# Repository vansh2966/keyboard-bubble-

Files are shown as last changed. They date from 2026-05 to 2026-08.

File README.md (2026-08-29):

well story behind is that i was always wanted mechanical keyboards, that cool looking keyboards with crazy 
lighting effects and keycaps. so i thought why not make one myself, i will learn lot new things, desgin my first PCB and also get myself my own custom keyboard. so started it, did some research, components 
and everything related to it

it a keyboard that helps u write with per key rgb which u can control and create some cool and awsome effects.
u can use it wired or wireless, with hotswappable keys. u can just change the type of keys if u wnat. 
all key anti ghost, with 65% layout and 68 keys which u can assign anything and also create macros.

in the base there highted screw holes, first u put the the stabalizers in the PCB then place the PCB on the heighted holes then the plate and screw it up with 4 m2 screws. if u want u can add a foam layer between
the PCB and the plate. and in the end u can add the keycaps.

**How to Build it**
- get all the matrials including 3d printed parts
- soldering all the things in PCB
- place your PCB in case aliging with the screw holes
- place your plate on top that, u can also palce foam btween plate and pcb.
- screw up all 4 screws
- take keys your keys and stick them
- put your keycaps on the top
- take your microcontroller and plug it in
- make sure its in bootloader mode
- take the firmware files and put them in the chip
- ready to use it

**How to use it**
- u can use it wired or wireselly
- connect it ur computer using cable or bluthooth
- start typing

baseee

the base of the keyboard. i wanted it look premium so i made the thick bezels, u can mount the pcb and plate with screws

complete
WhatsApp Image 2026-07-14 at 11 50 17 PM

this all together looks with brown and black keys. maybe i will change it later if i want 

the completed build with gengar themed keys:
WhatsApp Image 2026-07-14 at 11 50 19 PM
WhatsApp Image 2026-07-14 at 11 50 19 PM

bin
pcb
pcb back

the PCB  tool all of times, the scematics routing, fixing small errors and getting tons of errors in DRC. but in the end 
it was worth it

i updated the CAD file and made a new design. fixed few error that learned after ordering the old one. not muhc much of a change but ig its better and also looks better


## 📦 Bill of Materials (BOM)

| Component | Quantity | Total Price (INR) | Sourcing Link |
| :--- | :---: | :---: | :--- |
| **XIAO ESP32 nRF52840 Plus** | 1 | ₹2,300 | [Mouser Link](https://www.mouser.in/ProductDetail/Seeed-Studio/102010672?qs=sqEgtWRSLJ0SuHAgTfdO0A%3D%3D) |
| **3.7V Lithium Polymer Battery** | 1 | ₹397 | [Amazon Link](https://www.amazon.in/gp/product/B0GM6RKSB4/) |
| **Slide Switch (3-Pin)** | 1 | ₹100 | [Amazon Link](https://www.amazon.in/gp/product/B0D33BLGBB/) |
| **Mechanical Switches (Kailh Red)** | 70 | ₹1,260 | [Cosmic Byte Link](https://www.thecosmicbyte.com/product/kailh-mechanical-switches-for-swappable-keyboards-pack-of-10/) |
| **Kailh MX Hotswap Sockets** | 70 | ₹870 | [Neomacro Link](https://neomacro.in/products/kailh-mx-hotswap-socket) |
| **Diodes (1N4148W)** | 100 | ₹1,944 | [DigiKey Link](https://www.digikey.in/en/products/detail/mcc-micro-commercial-components/1N4148W-TP/717196) |
| **Stabilizers (PCB Mount)** | 1 | ₹2,400 | [Amazon Link](https://www.amazon.in/gp/product/B07K8HP6KC/) |
| **Keycaps** | 1 | ₹5,335 | [Amazon Link](https://www.amazon.in/gp/product/B0FS27BG38/) |
| **LEDs (SK6812 Mini-E Reverse)** | 100 | ₹6,310 | [Amazon Link](https://www.amazon.in/gp/product/B0D5LGQ629/) |
| **Decoupling Capacitors** | 100 | ₹100 | [Robu Link](https://robu.in/product/1uf-capacitor-smdc-0402-pack-of-50/) |
| **Transistor (SM712 TVS)** | 1 | ₹28 | [DigiKey Link](https://www.digikey.in/en/products/detail/smc-diode-solutions/SM712/16584910) |
| **PCB Fabrication** | 1 | ₹5,918 | [JLCPCB Link](https://jlcpcb.com) |
| **3D Printing Service** | 2 | ₹1,729 | [Robu Link](https://robu.in/product/3d-printing-service1/) |
| **Resistors** | 2 | Already have it | - |
| **2 in 1 Hot Wind Gun Solder Iron SMD Rework Soldering Station ** | 1 | ₹4391 | [Amazon Link](https://www.amazon.in/gp/product/B0F4QYBK7Y/ref=ox_sc_act_title_1?smid=A3T8K809Q96RB6&psc=1) |
| **Soldering paste** | 1 | ₹399 | [Amazon link](https://www.amazon.in/gp/product/B0DL4K4WWQ/ref=ox_sc_act_title_1?smid=A28W8MJHJ0JA2F&psc=1) | 
| **Miscellaneous** | - | ₹1,000 | - |
| ─── | ─── | ─── | ─── |
| **TOTAL COST** | **-** | **₹34,482 ($361 USD)** | **Fully Sourced** |

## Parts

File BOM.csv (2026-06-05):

COMPONENT | QTY | price | link
XIAO ESP32 nRF52840 plus | 1 | 2300 | https://www.mouser.in/ProductDetail/Seeed-Studio/102010672?qs=sqEgtWRSLJ0SuHAgTfdO0A%3D%3D
3.7V Lithium Polymer Battery | 1 | 397 | https://www.amazon.in/gp/product/B0GM6RKSB4/ref=ox_sc_act_title_5?smid=A3QQB9C2QXM7ZJ&psc=1
slide swtich 3pin | 1 | 100 | https://www.amazon.in/gp/product/B0D33BLGBB/ref=ox_sc_act_title_2?smid=A1UUD7CBBVVXIG&psc=1
Mechanical Switches | 70 | 1260 | https://www.thecosmicbyte.com/product/kailh-mechanical-switches-for-swappable-keyboards-pack-of-10/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
Kailh Hotswap Sockets | 70 | 870 | https://neomacro.in/products/kailh-mx-hotswap-socket?variant=49467139227926&country=IN&currency=INR
Diodes (1N4148W) | 100 | 1944 | https://www.digikey.in/en/products/detail/mcc-micro-commercial-components/1N4148W-TP/717196
Stabilizers (PCB mount) | 1 | 2400 | https://www.amazon.in/gp/product/B07K8HP6KC/ref=ox_sc_act_title_3?smid=AKPH4HW0FR8BT&psc=1
Keycaps | 1 | 5,335 | https://www.amazon.in/gp/product/B0FS27BG38/ref=ox_sc_act_title_4?smid=A2IJXLCHRFK9Q6&th=1
LED (SK6812 Mini-E) reverse | 100 | 6,310 | https://www.amazon.in/gp/product/B0D5LGQ629/ref=ox_sc_act_title_6?smid=A473XUTYXHG1Q&psc=1
Decoupling Capacitors | 100 | 100 | https://robu.in/product/1uf-capacitor-smdc-0402-pack-of-50/
Transistor | 1 | 28 | https://www.digikey.in/en/products/detail/smc-diode-solutions/SM712/16584910
PCB | 1 | 5,918 | https://jlcpcb.com
3D printitng | 2 | 1,729.00 | https://robu.in/product/3d-printing-service1/
resistors | 2 | already have it
soldering paste | 1 | 399 | https://www.amazon.in/gp/product/B0DL4K4WWQ/ref=ox_sc_act_title_1?smid=A28W8MJHJ0JA2F&psc=1
2 in 1 Hot Wind Gun Solder Iron SMD Rework Soldering Station |  | 4391 | https://www.amazon.in/gp/product/B0F4QYBK7Y/ref=ox_sc_act_title_1?smid=A3T8K809Q96RB6&psc=1
miscellaneous |  | 1000
TOTAL |  | 34482(361$)

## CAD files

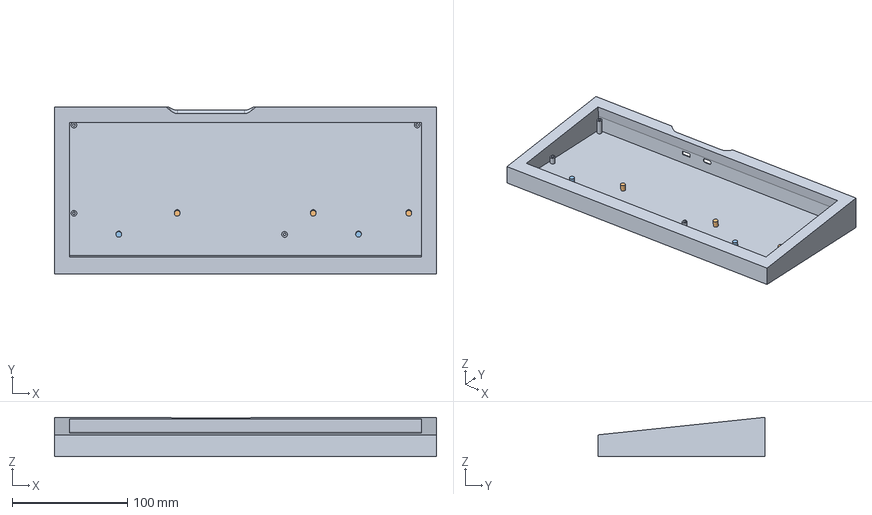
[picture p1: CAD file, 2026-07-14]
CAD/keyboard_base_new.step
332.0 x 145.4 x 34.3 mm

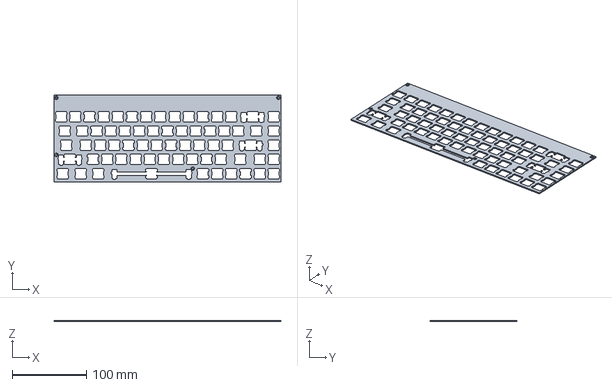
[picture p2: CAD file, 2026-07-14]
CAD/keyboard_plate_new.step
304.8 x 117.4 x 1.50 mm

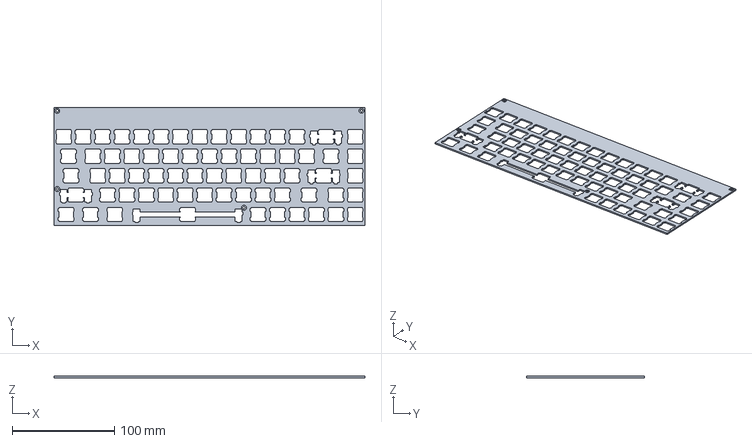
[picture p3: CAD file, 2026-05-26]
CAD/keyboard_plate.step
304.8 x 115.8 x 1.50 mm

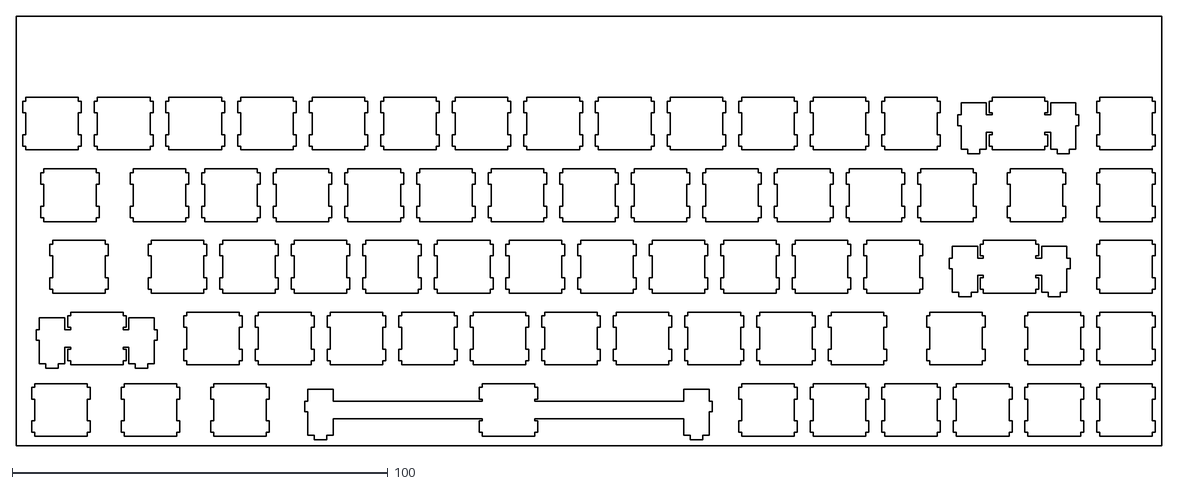
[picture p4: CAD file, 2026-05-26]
CAD/359b55f85a813e9f2932e763c449902111d80da4_switch.dxf
304.8 x 114.3

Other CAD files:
CAD/keyboard_base.step
CAD/keyboard_base.f3d
CAD/keyboard_plate.f3d
STL files/keyboard_base.stl
STL files/keyboard_plate.stl

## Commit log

2026-05-22 Create PCB
2026-05-26 Create CAD
2026-07-14 Update CAD README.md
